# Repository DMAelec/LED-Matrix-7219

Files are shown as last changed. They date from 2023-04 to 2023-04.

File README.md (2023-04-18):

# LED Matrix 7219

## Introduction
The LED Matrix 7219 is a serial controlled 8x8 display using individual LED's. Displays can be cascadable up to 8 modules and you can use any
through hole LED's. Pitch between LED's is 7.62mm(0.3"). The Matrix is wired up to match the FC-16 type modules and is standard Arduino code is compatible.

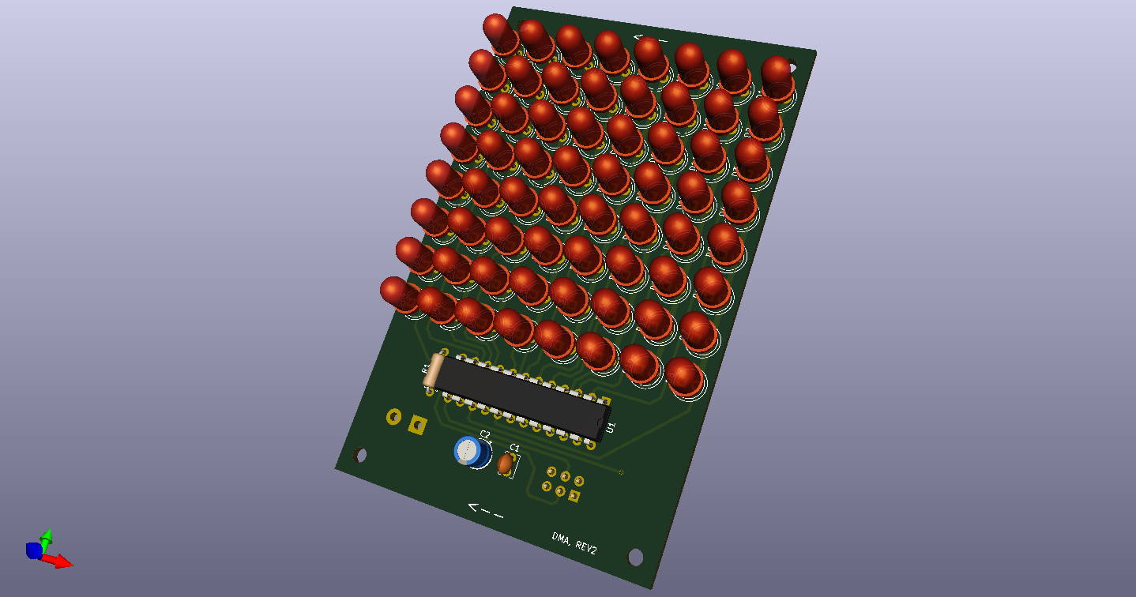
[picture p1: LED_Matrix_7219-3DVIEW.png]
3DVIEW


## Bill of Materials
Reference | Description                         | Part No.  
----------|-------------------------------------|----------------
D1-D64    | 5mm LED, Diffused                   | (Red)LTL2R3KRD-EM (Yellow)LTL2R3KYD-EM (Green)LTL2R3KGD-EM
U1        | LED Display Driver IC, PDIP-24      | MAX7219CNG+
R1        | 30KOhm, 1/4W, Resistor              | CFR-25JB-52-30K
C1        | 0.1uF, 50v, MLCC                    | K104K15X7RF5TL2
C2        | 10uF, 25V, Elec Capacitor           | ECE-A1EKS100I
J1        | Terminal block, 2 pos, 5.08mm       | TB007-508-02BE
J2        | Pin Header, 6 pos, 2 row, Straight  | 67996-106HLF
Misc      | Wire Housing, 6 pos, 2 row          | M20-1070300
Misc      | Crimp, 30 AWG to 22 AWG             | M20-1160042

NOTE: R1= Iset Value, Example given 1.5Vf at 20mA. See MAX7219 datasheet for full table.

## Changes
* Revision 2.0
  * Complete board redesign
  * Fixed LED origin point 
  * Added extra bypass capacitors for U1

* Revision 1.0
  * Initial version

## Links

[FC-16 wiring info](https://majicdesigns.github.io/MD_MAX72XX/page_f_c16.html)

[Arduino Library](https://reference.arduino.cc/reference/en/libraries/md_max72xx/)

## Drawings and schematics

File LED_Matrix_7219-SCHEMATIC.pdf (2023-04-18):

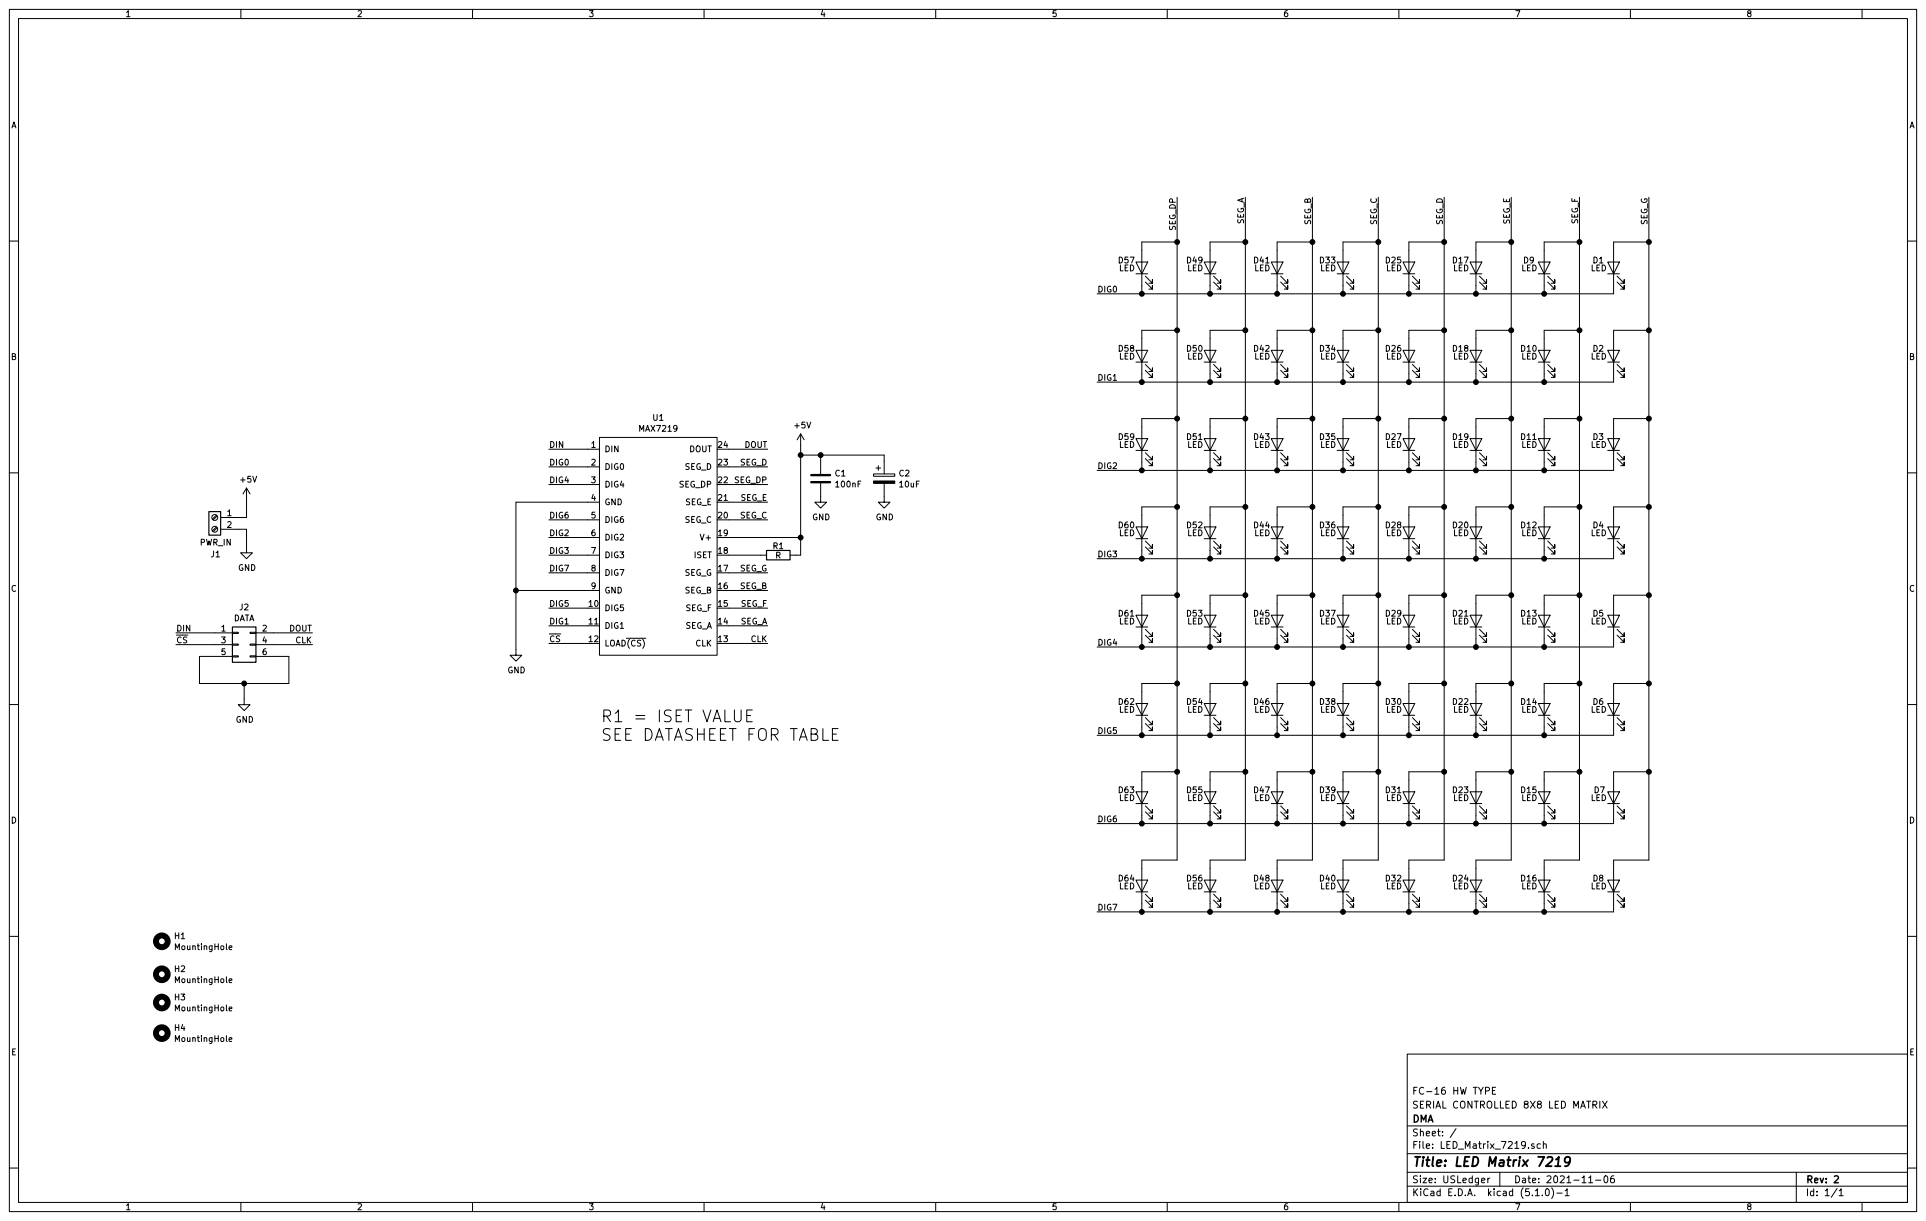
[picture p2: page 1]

SEE DATASHEET FOR TABLE

FC-16 HW TYPE
SERIAL CONTROLLED 8X8 LED MATRIX
File: LED_Matrix_7219.sch Sheet: / DMA

Id: 1/1 Title: LED Matrix 7219

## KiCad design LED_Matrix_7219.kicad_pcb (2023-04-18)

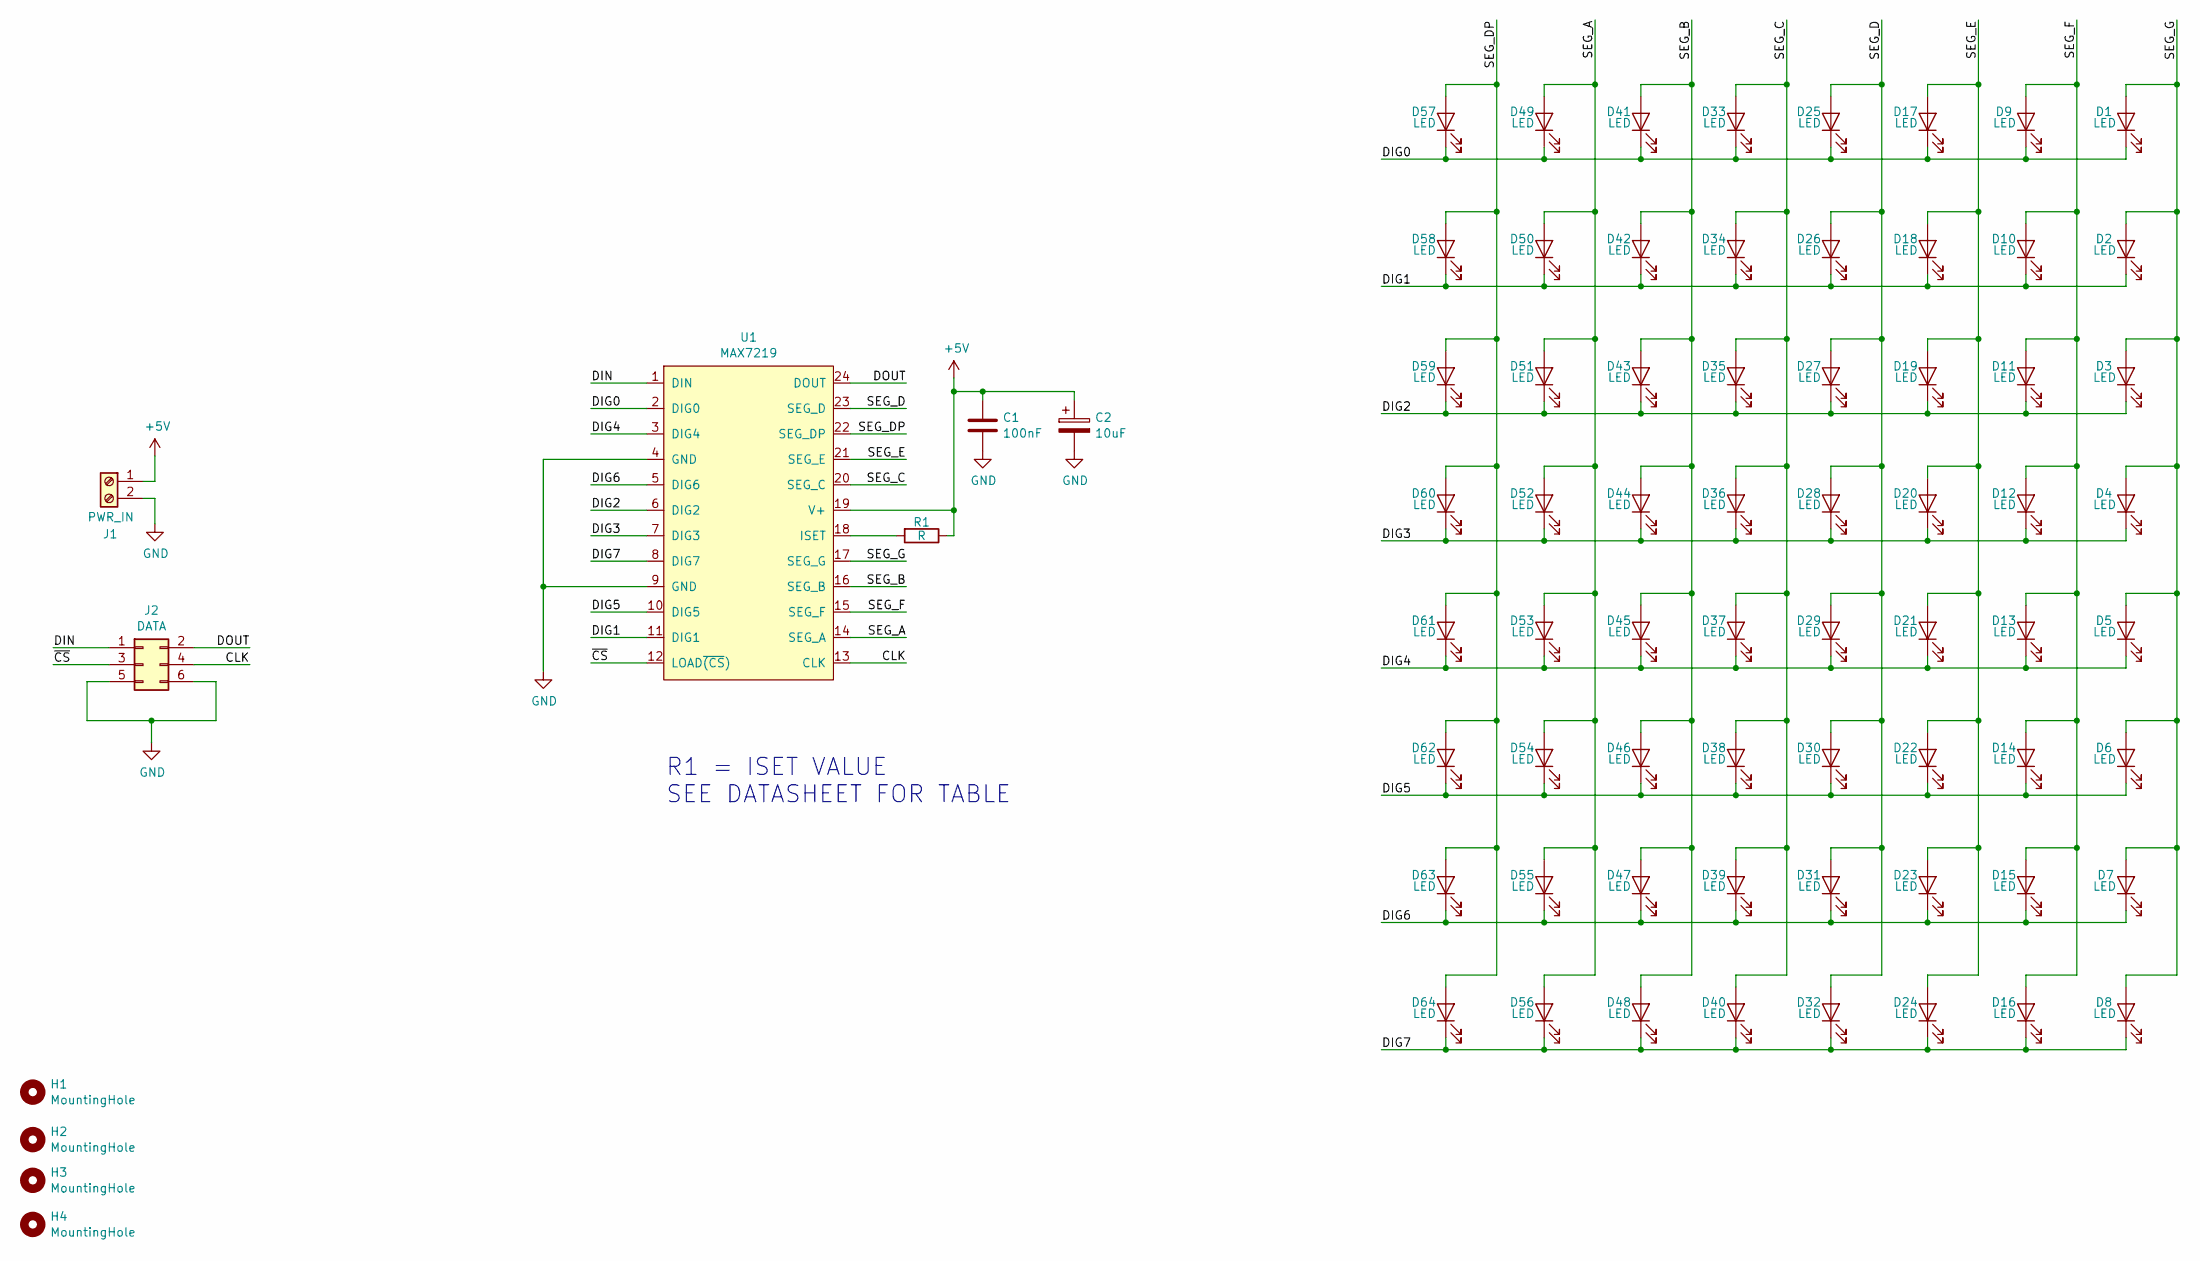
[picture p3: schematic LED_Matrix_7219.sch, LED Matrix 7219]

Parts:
C1: 100nF; C_Disc_D3.8mm_W2.6mm_P2.50mm
C2: 10uF; CP_Radial_D5.0mm_P2.50mm
D1, D2, D3, D4, D5, D6, D7, D8, D9, D10, D11, D12, D13, D14, D15, D16, D17, D18, D19, D20, D21, D22, D23, D24, D25, D26, D27, D28, D29, D30, D31, D32, D33, D34, D35, D36, D37, D38, D39, D40, D41, D42, D43, D44, D45, D46, D47, D48, D49, D50, D51, D52, D53, D54, D55, D56, D57, D58, D59, D60, D61, D62, D63, D64: LED; LED_D5.0mm
H1, H2, H3, H4: MountingHole; MountingHole_2.7mm_M2.5
J1: PWR_IN; TerminalBlock_bornier-2_P5.08mm
J2: DATA; PinHeader_2x03_P2.54mm_Vertical
R1: R; R_Axial_DIN0207_L6.3mm_D2.5mm_P7.62mm_Horizontal
U1: MAX7219; DIP-24_W7.62mm

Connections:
+5V: C1.1, C2.1, J1.1, R1.1, U1.19 (V+)
/CLK: J2.4, U1.13 (CLK)
/DIG0: D1.1 (K), D9.1 (K), D17.1 (K), D25.1 (K), D33.1 (K), D41.1 (K), D49.1 (K), D57.1 (K), U1.2 (DIG0)
/DIG1: D2.1 (K), D10.1 (K), D18.1 (K), D26.1 (K), D34.1 (K), D42.1 (K), D50.1 (K), D58.1 (K), U1.11 (DIG1)
/DIG2: D3.1 (K), D11.1 (K), D19.1 (K), D27.1 (K), D35.1 (K), D43.1 (K), D51.1 (K), D59.1 (K), U1.6 (DIG2)
/DIG3: D4.1 (K), D12.1 (K), D20.1 (K), D28.1 (K), D36.1 (K), D44.1 (K), D52.1 (K), D60.1 (K), U1.7 (DIG3)
/DIG4: D5.1 (K), D13.1 (K), D21.1 (K), D29.1 (K), D37.1 (K), D45.1 (K), D53.1 (K), D61.1 (K), U1.3 (DIG4)
/DIG5: D6.1 (K), D14.1 (K), D22.1 (K), D30.1 (K), D38.1 (K), D46.1 (K), D54.1 (K), D62.1 (K), U1.10 (DIG5)
/DIG6: D7.1 (K), D15.1 (K), D23.1 (K), D31.1 (K), D39.1 (K), D47.1 (K), D55.1 (K), D63.1 (K), U1.5 (DIG6)
/DIG7: D8.1 (K), D16.1 (K), D24.1 (K), D32.1 (K), D40.1 (K), D48.1 (K), D56.1 (K), D64.1 (K), U1.8 (DIG7)
/DIN: J2.1, U1.1 (DIN)
/DOUT: J2.2, U1.24 (DOUT)
/SEG_A: D49.2 (A), D50.2 (A), D51.2 (A), D52.2 (A), D53.2 (A), D54.2 (A), D55.2 (A), D56.2 (A), U1.14 (SEG_A)
/SEG_B: D41.2 (A), D42.2 (A), D43.2 (A), D44.2 (A), D45.2 (A), D46.2 (A), D47.2 (A), D48.2 (A), U1.16 (SEG_B)
/SEG_C: D33.2 (A), D34.2 (A), D35.2 (A), D36.2 (A), D37.2 (A), D38.2 (A), D39.2 (A), D40.2 (A), U1.20 (SEG_C)
/SEG_D: D25.2 (A), D26.2 (A), D27.2 (A), D28.2 (A), D29.2 (A), D30.2 (A), D31.2 (A), D32.2 (A), U1.23 (SEG_D)
/SEG_DP: D57.2 (A), D58.2 (A), D59.2 (A), D60.2 (A), D61.2 (A), D62.2 (A), D63.2 (A), D64.2 (A), U1.22 (SEG_DP)
/SEG_E: D17.2 (A), D18.2 (A), D19.2 (A), D20.2 (A), D21.2 (A), D22.2 (A), D23.2 (A), D24.2 (A), U1.21 (SEG_E)
/SEG_F: D9.2 (A), D10.2 (A), D11.2 (A), D12.2 (A), D13.2 (A), D14.2 (A), D15.2 (A), D16.2 (A), U1.15 (SEG_F)
/SEG_G: D1.2 (A), D2.2 (A), D3.2 (A), D4.2 (A), D5.2 (A), D6.2 (A), D7.2 (A), D8.2 (A), U1.17 (SEG_G)
/~CS: J2.3, U1.12 (LOAD~(CS))
GND: C1.2, C2.2, J1.2, J2.5, J2.6, U1.4 (GND), U1.9 (GND)
unnamed: R1.2, U1.18 (ISET)

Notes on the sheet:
R1 = ISET VALUE SEE DATASHEET FOR TABLE

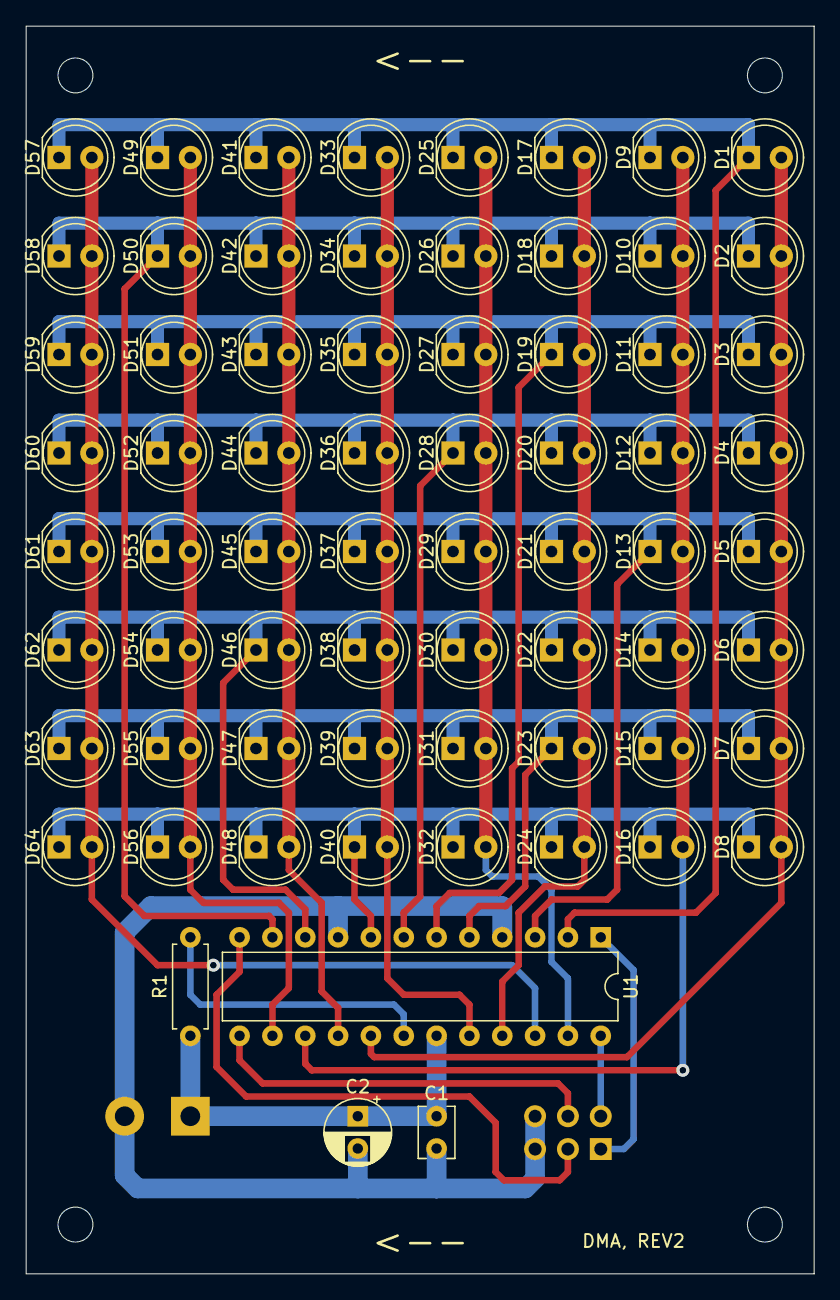
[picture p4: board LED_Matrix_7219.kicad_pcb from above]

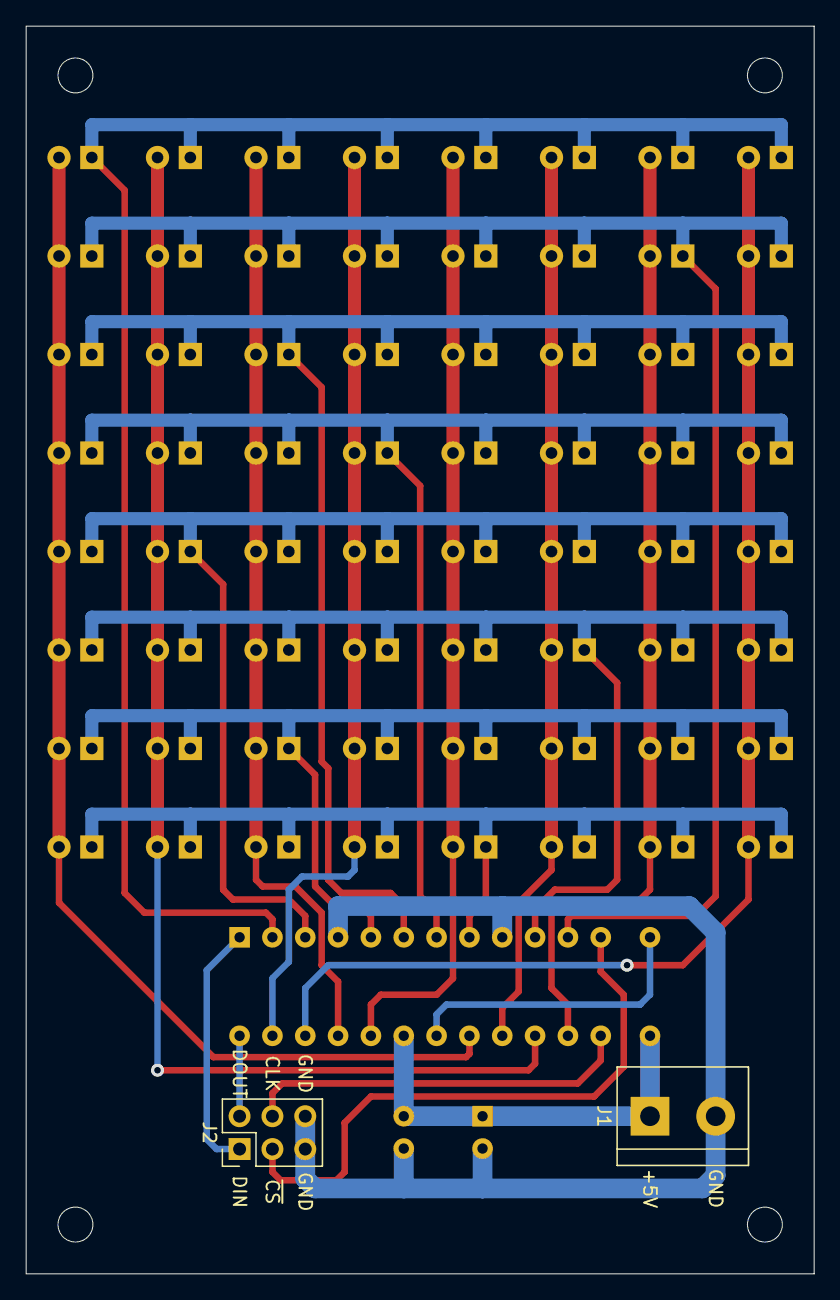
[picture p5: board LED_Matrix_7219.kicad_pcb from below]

Board: 2 copper layers, 61.0 x 96.5 mm, 74 parts (2 on the bottom side), 23 nets.
